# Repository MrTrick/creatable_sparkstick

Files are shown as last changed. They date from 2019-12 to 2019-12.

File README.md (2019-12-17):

# creatable_sparkstick
OSHW designs for the Spark Stick ATTiny85 development board.

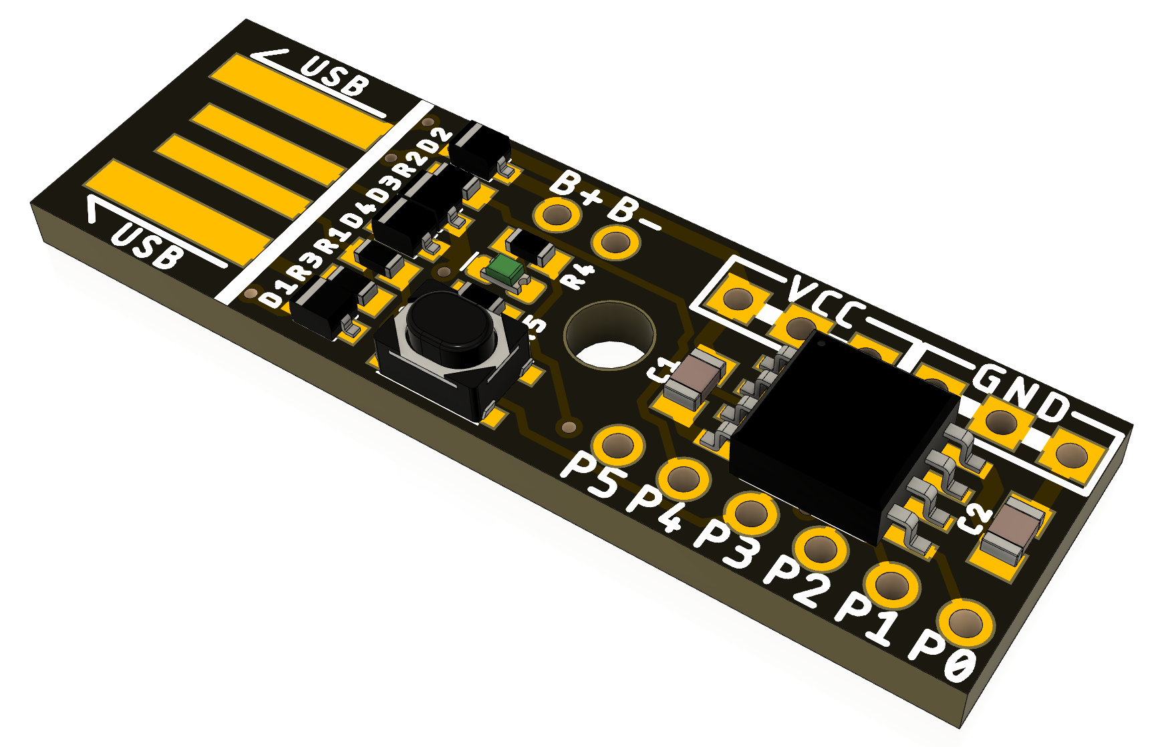
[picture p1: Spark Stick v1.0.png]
Spark Stick v1.0


## Software
See https://github.com/nakatomi/creatable_srl

## License 
https://creativecommons.org/licenses/by-sa/3.0/

## Limitations
The Creatable and Spark Stick names and logos (or derivatives
thereof) may not be used as part of the name of a product,
company or domain name without express written permission.

## Disclaimer
Note: Schematics, source files, software, and datasheets are provided rovided "as is", without warranty of any kind, express or implied, including but not limited to the warranties of merchantability, fitness for a particular purpose and noninfringement. in no event shall the authors or copyright holders be liable for any claim, damages or other liability, whether in an action of contract, tort or otherwise, arising from, out of or in connection with the product or the use or other dealings in these products.

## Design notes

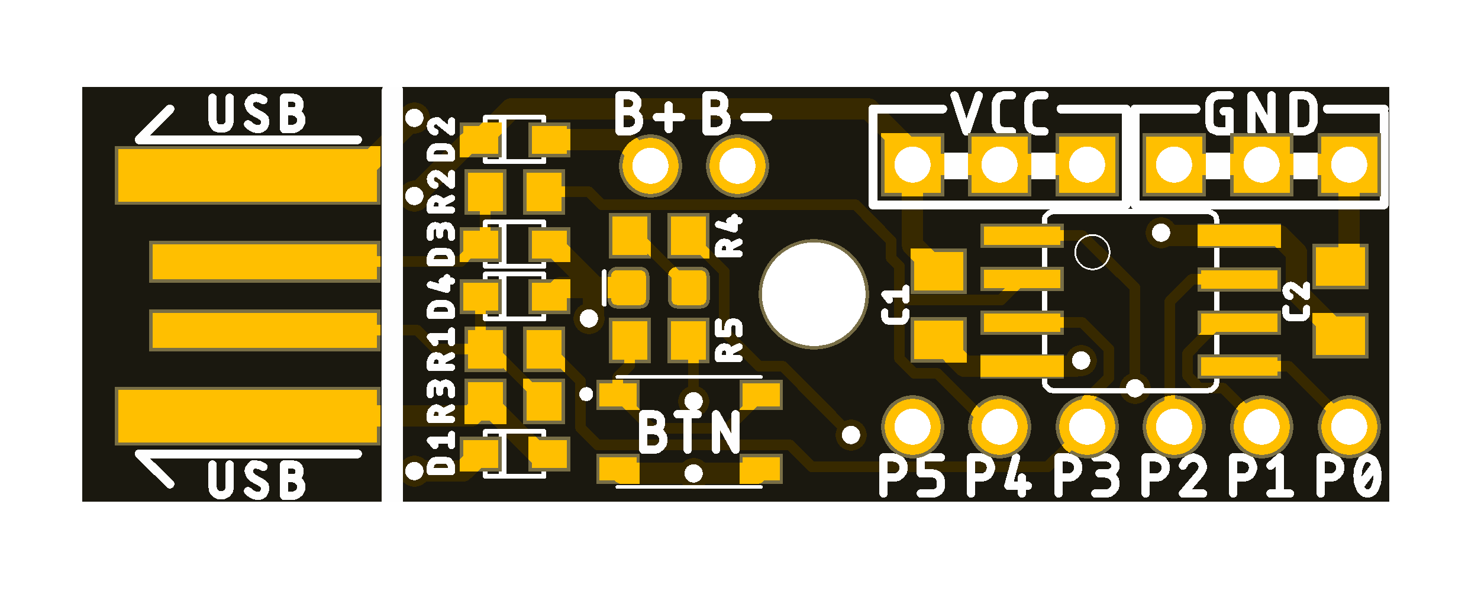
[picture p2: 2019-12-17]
Spark Stick v1.0 top.png

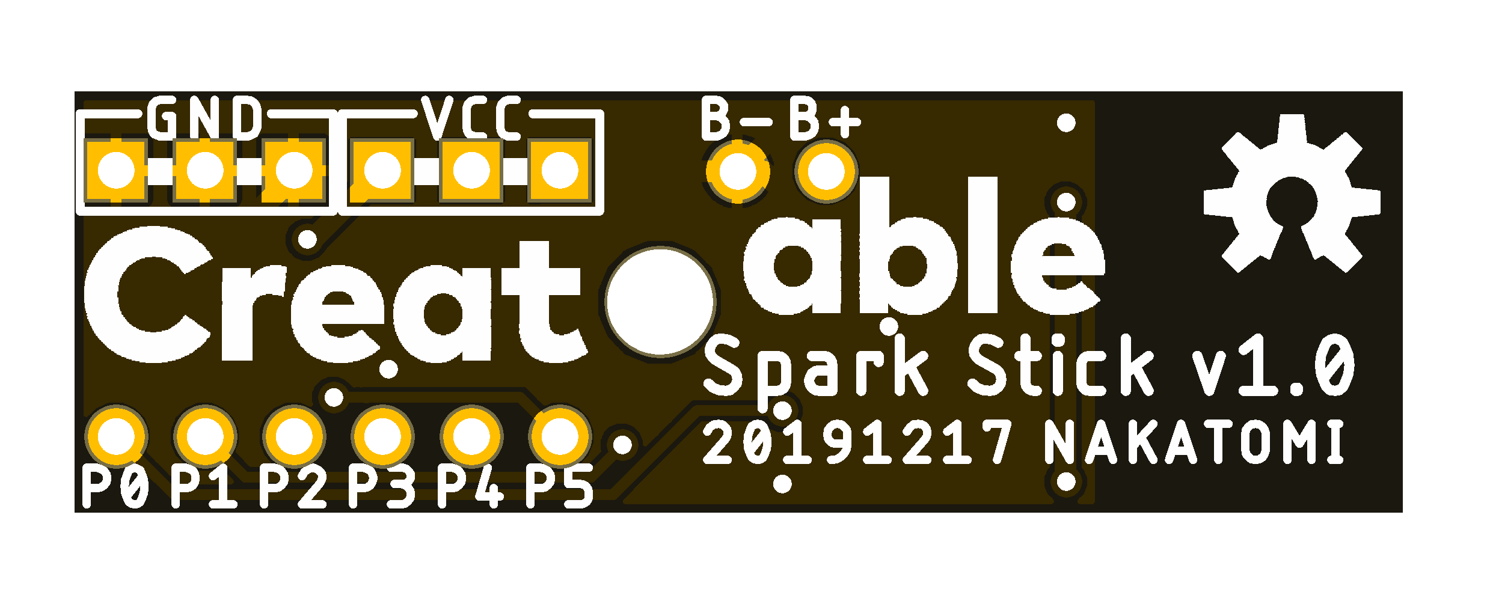
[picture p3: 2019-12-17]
Spark Stick v1.0 bottom.png

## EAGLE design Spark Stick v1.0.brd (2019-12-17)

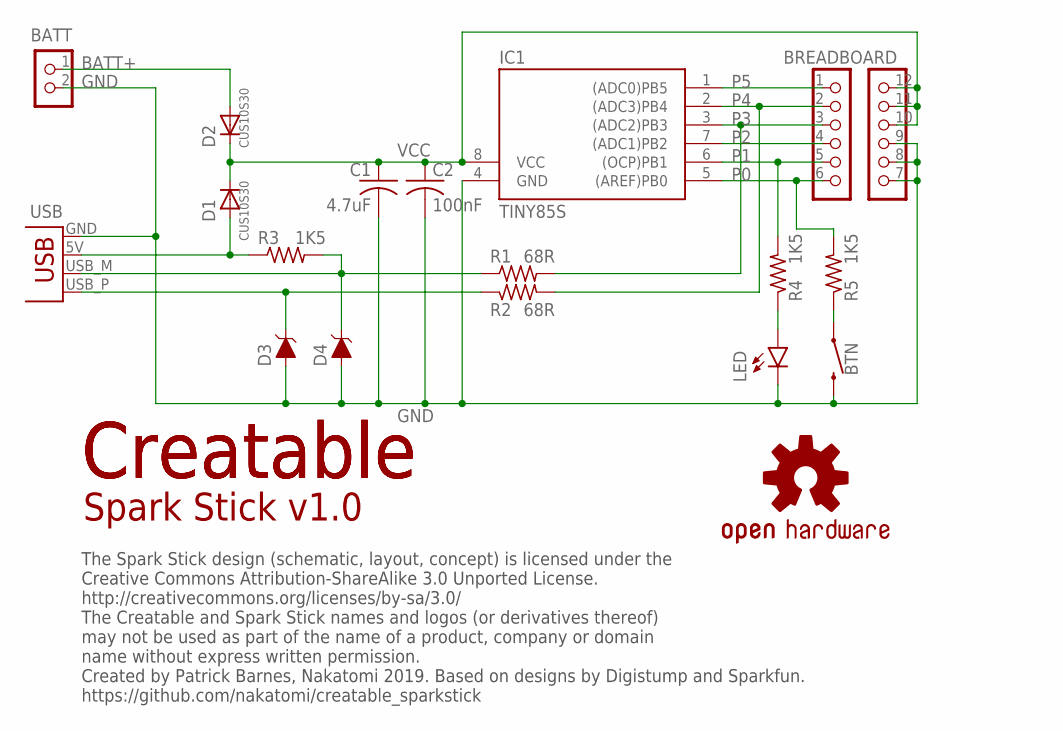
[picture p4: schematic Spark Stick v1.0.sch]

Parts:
BATT: CON_HEADER_1X02ROUND; CON_HEADER_M1X2_ROUND
BREADBOARD: CON_HEADER_2X06; CON_HEADER_M2X6_BREADBOARD
BTN: MOMENTARY-SWITCH-SPST-PTS810; PTS810SJG250SMTRLFS; LCSC_ID C221897
C1: 4.7uF; C0805K; LCSC_ID C107365
C2: 100nF; C0805K; LCSC_ID C1760
D1, D2: CUS10S30; SOD-323F; LCSC_ID C146335
D3, D4: DIODE-ZENER-SOD-323F; SOD-323F; LCSC_ID C353525
IC1: TINY85S; SOIC8; MPN ATTINY85-20SU; LCSC_ID C89852
LED: RED LED; LED-0603; LCSC_ID C125094
LOGO1: OSHW-LOGOM; OSHW-LOGO-M
LOGO_2A: LOGO_CREATABLECREAT; LOGO_CREATABLE_CREAT
LOGO_2B: LOGO_CREATABLEABLE; LOGO_CREATABLE_ABLE
R1, R2: 68R; R0603; LCSC_ID C192544
R3, R4, R5: 1K5; R0603; LCSC_ID C118361
USB: MICRO USB; SPARKFUN-CONNECTORS_USB-A-PCB

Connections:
BATT+: BATT.1, D2.A
BTN: BTN.1, BTN.2 (1), R5.1
D+: D3.C, R2.1, USB.USB_P (D+)
D-: D4.C, R1.1, R3.2, USB.USB_M (D-)
GND: BATT.2, BREADBOARD.7, BREADBOARD.8, BREADBOARD.9, BTN.3 (2), BTN.4 (2), C1.2, C2.2, D3.A, D4.A, IC1.4 (GND), LED.C, USB.GND
LED: LED.A, R4.1
P0: BREADBOARD.6, IC1.5 ((AREF)PB0), R5.2
P1: BREADBOARD.5, IC1.6 ((OCP)PB1), R4.2
P2: BREADBOARD.4, IC1.7 ((ADC1)PB2)
P3: BREADBOARD.3, IC1.3 ((ADC2)PB3), R1.2
P4: BREADBOARD.2, IC1.2 ((ADC3)PB4), R2.2
P5: BREADBOARD.1, IC1.1 ((ADC0)PB5)
VBUS: D1.A, R3.1, USB.5V (VBUS)
VCC: BREADBOARD.10, BREADBOARD.11, BREADBOARD.12, C1.1, C2.1, D1.C, D2.C, IC1.8 (VCC)

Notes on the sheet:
The Spark Stick design (schematic, layout, concept) is licensed under the Creative Commons Attribution-ShareAlike 3.0 Unported License. http://creativecommons.org/licenses/by-sa/3.0/ The Creatable and Spark Stick names and logos (or derivatives thereof) may not be used as part of the name of a prod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
Spark Stick v1.0

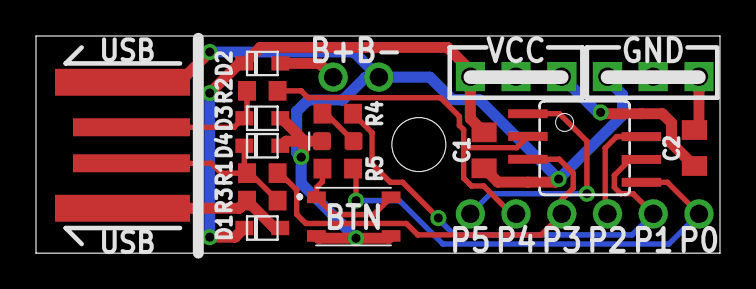
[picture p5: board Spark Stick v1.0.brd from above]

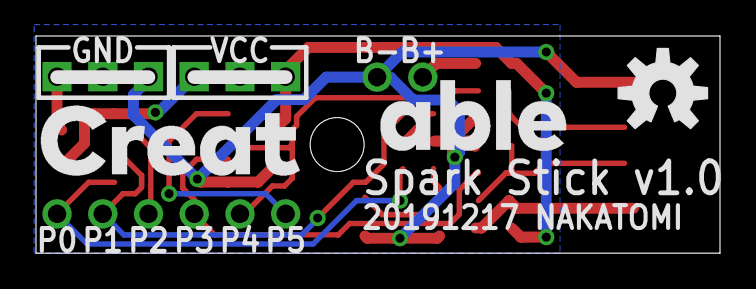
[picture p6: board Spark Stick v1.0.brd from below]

Board: 2 copper layers, 38.0 x 12.1 mm, 20 parts (3 on the bottom side), 14 nets.

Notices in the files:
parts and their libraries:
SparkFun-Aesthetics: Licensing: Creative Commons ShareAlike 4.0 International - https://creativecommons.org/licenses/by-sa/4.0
